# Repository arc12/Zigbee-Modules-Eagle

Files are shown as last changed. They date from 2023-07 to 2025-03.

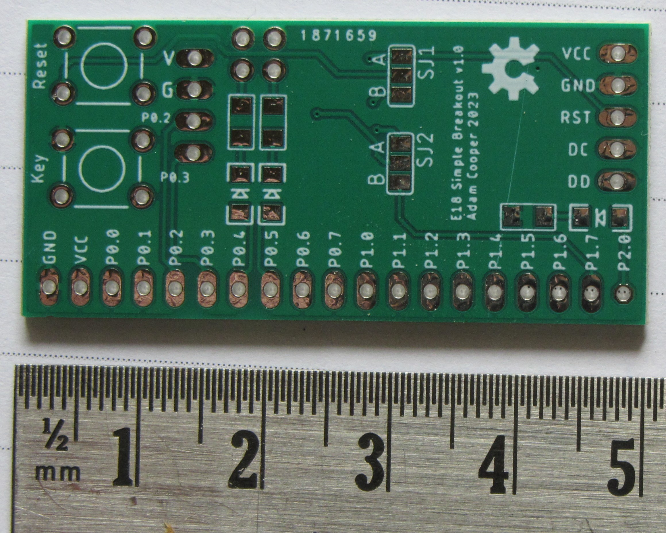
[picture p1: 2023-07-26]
E18 Front.JPG

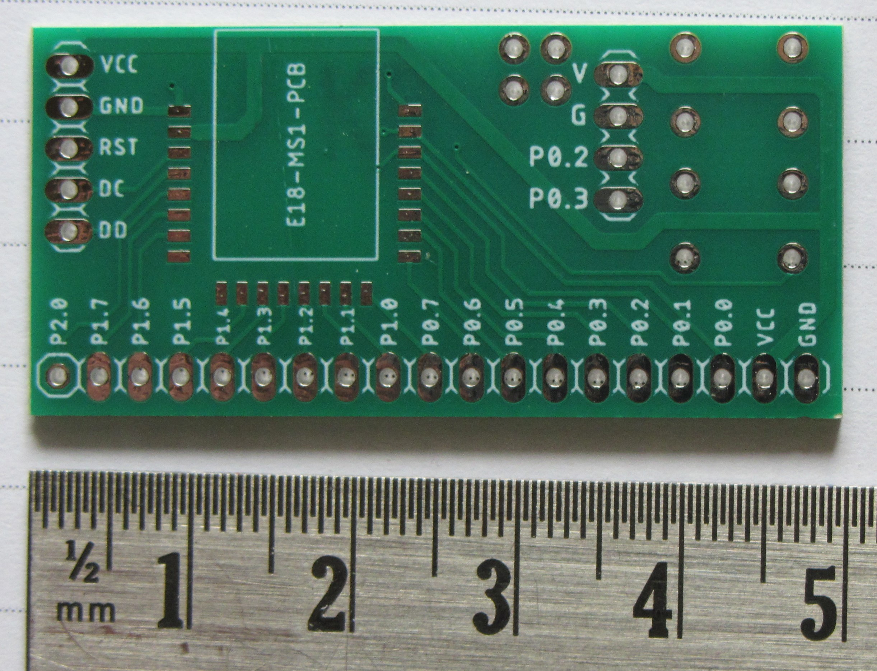
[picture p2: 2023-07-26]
E18 Rear.JPG

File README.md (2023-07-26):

# Zigbee Modules Eagle
## E18 Simple Breakout
A simple breakout board for the Ebyte E18 MS1 "stamp" module (i.e. a version without the extra power amplifier). The device shown is the PCB variant but AFAIK the landing pattern is identical for the IPX variant. The PA1/PA2 versions of E18 include a power amplifier and have a slightly larger landing pattern which probably won't fit (try at your own risk!).

This is "simple" in that the main use case is to plug into breadboard; although there are some components other than the E18 on the board, these are included for possible convenience (and using available board space).

Some notes on motivation, layout pragmatics, and options:
- The long header is meant to be populated with right-angle pins. This will put the antenna nicely up and leaves plenty of space for other components on the breadboard (I find the breakouts with very wide dual-in-line pin-outs to be rather irritating, and Arduino style sockets and flying leads are not great when more than a few connections are to be made).
- The 5 pin header is for firmware flashing. I opted for this, rather than the full 10 pin "debug" header which CCDebugger uses, for econonmy of space. These 5 pins are quite sufficient for using CCDebugger with TI SmartRF Flash Programmer (I made a little adapter) or if using something like https://github.com/jmichault/flash_cc2531 (or my patched version for use with Pi v1 GPIOs at https://github.com/arc12/flash_cc2531).
- The 4 pin header may be convenient for either UART or I2C connections. I'm expecting to be using PTVO and for the CC2530 it fixes UART pins to be P0.2 and P0.3. This header is meant to be mounted on the same side as the E18 module (opposite to switches).
- The switches should be configured using the solder jumpers.
  - SJ1 handles the "Reset" button: A connects to E18 Reset; B connects to P0.0.
  - SJ2 handles the "Key" button: A connects to P0.1; B connects to P1.7 (which is used by the E18 factory firmware).
- The on-board LEDs (and the enabling jumpers) should visually correlate with the pins they are connected to: P0.4, P0.5, and P2.0. These are NOT the same as used by the factory firmware. P2.0 LED has no enabling jumper.

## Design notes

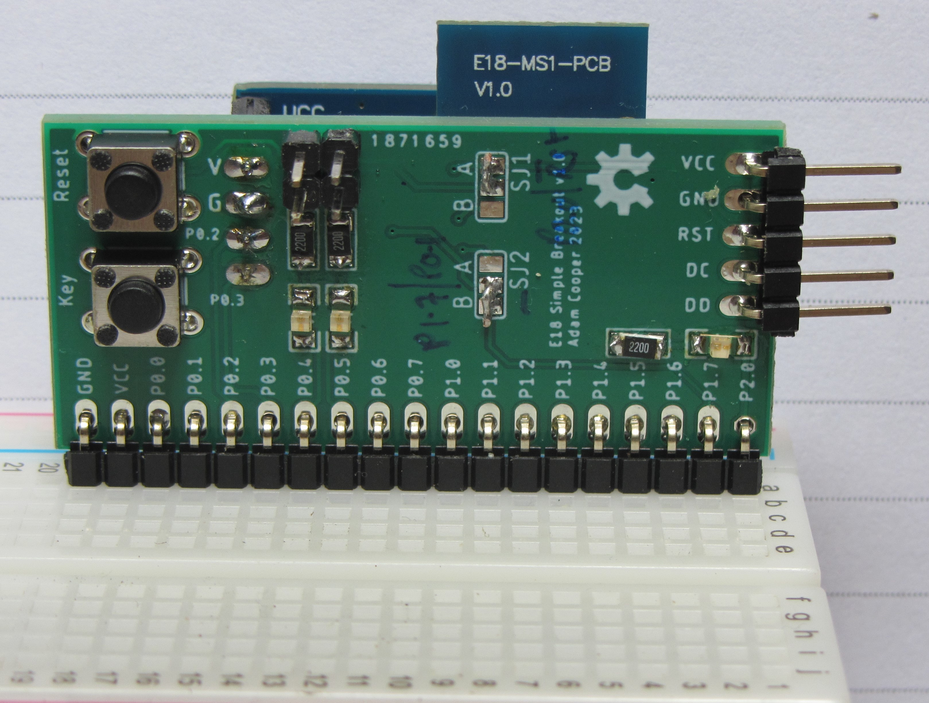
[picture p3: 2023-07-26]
E18 Populated.JPG

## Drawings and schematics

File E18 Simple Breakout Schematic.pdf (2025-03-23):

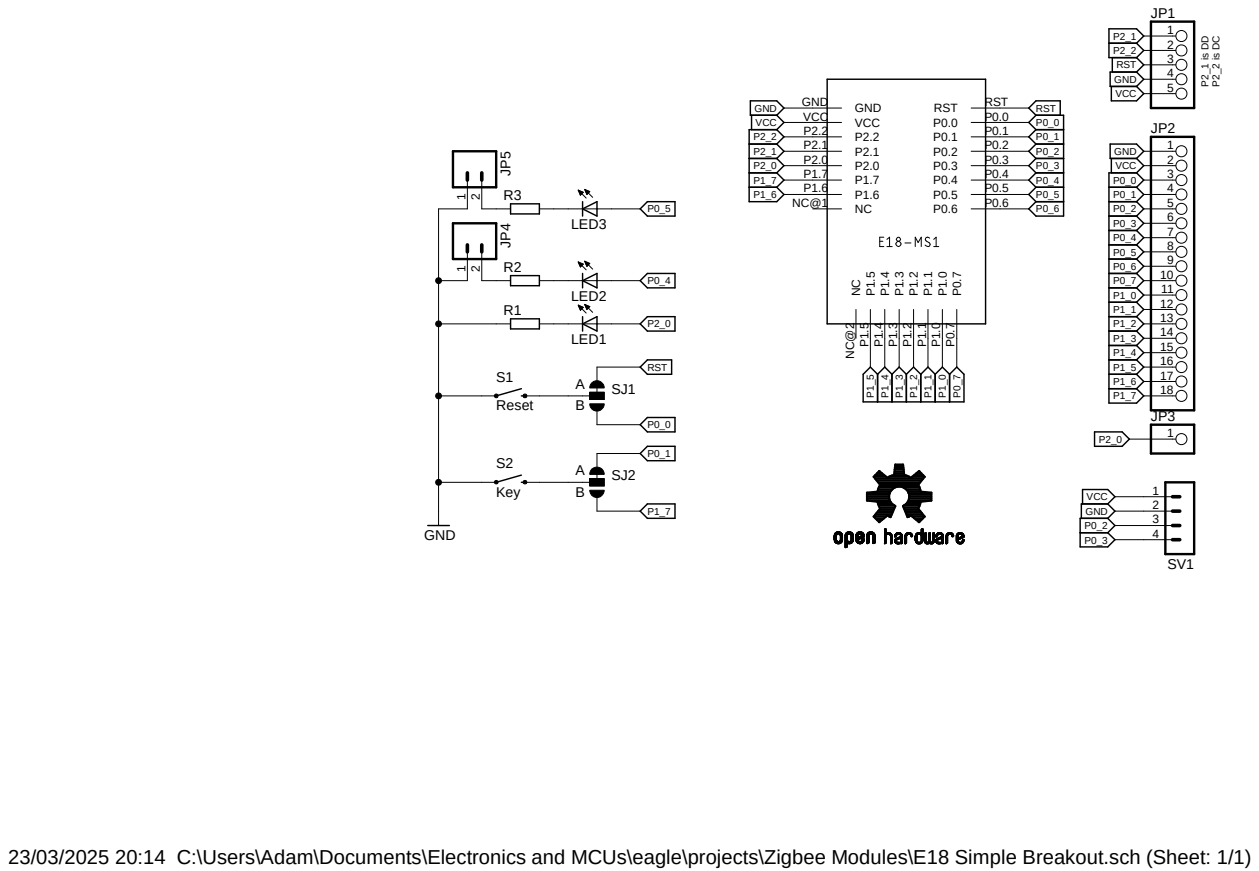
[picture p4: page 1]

23/03/2025 20:14 C:\Users\Adam\Documents\Electronics and MCUs\eagle\projects\Zigbee Modules\E18 Simple Breakout.sch (Sheet: 1/1) P²_1 is DD P²_2 is DC

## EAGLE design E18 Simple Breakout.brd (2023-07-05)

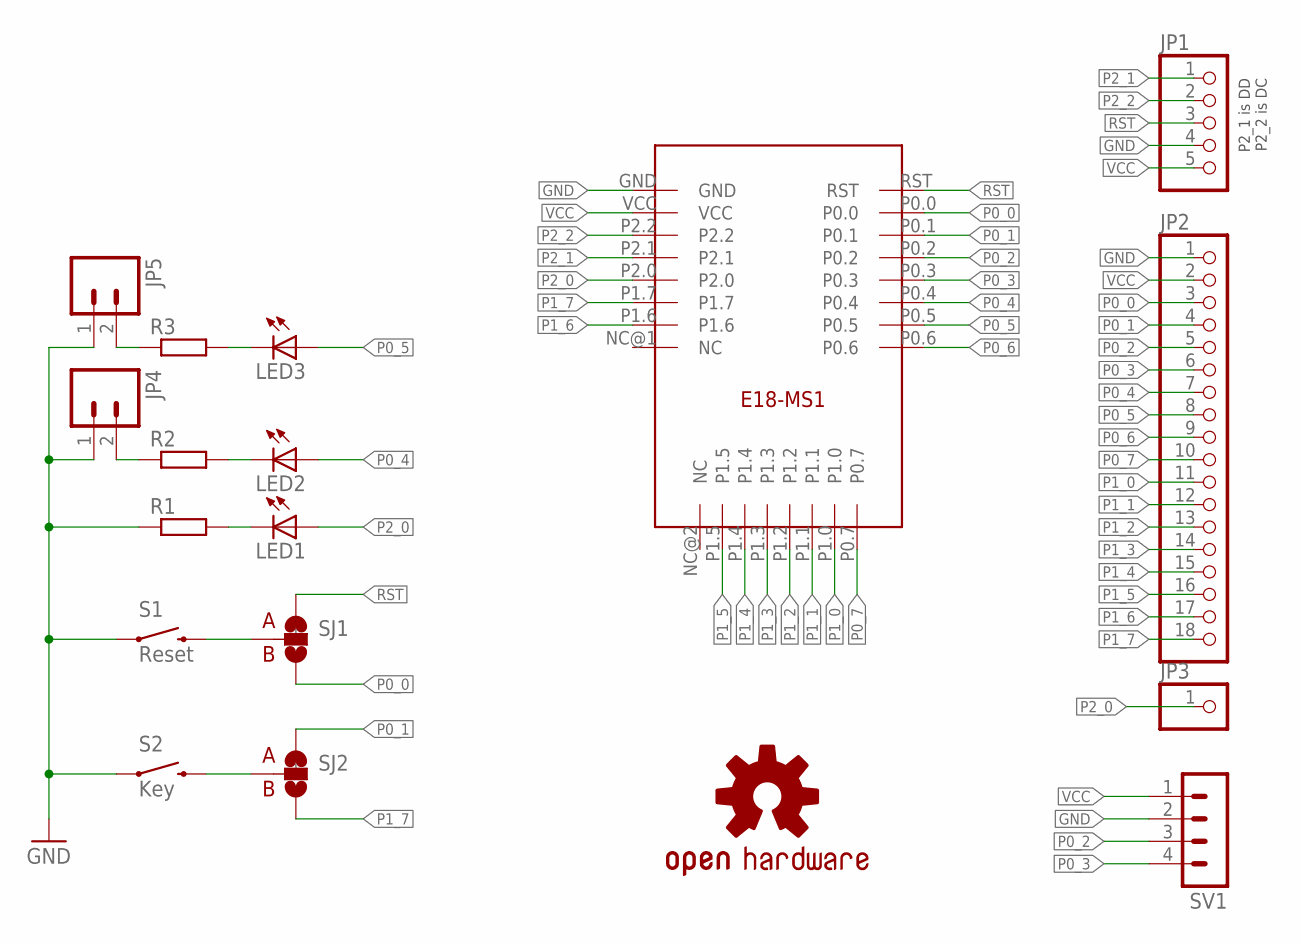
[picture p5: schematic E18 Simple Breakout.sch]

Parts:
JP1: PINHD-1X5; 1X05
JP2: PINHD-1X18; 1X18
JP3: PINHD-1X1; 1X01
JP4, JP5: HEADER-1X2P1X02_NO_SILK; 1X02_NO_SILK
LED1, LED2, LED3: LED1206; LED-1206
LOGO1: OSHW-LOGOM; OSHW-LOGO-M
R1, R2, R3: R-EU_; 1206
S1: Reset; TACTILE-PTH
S2: Key; TACTILE-PTH
SJ1, SJ2: SOLDERJUMPER_2WAYT; SJ_2
SV1: HEADER-1X4P; MA04-1
U$1: E18-MS1PCB; E18-MS1-PCB

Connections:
GND: JP1.4, JP2.1, JP4.1, JP5.1, R1.1, S1.1, S2.1, SV1.2, U$1.GND
unnamed: LED3.C, R3.2
unnamed: S1.3 (2), SJ1.2
unnamed: JP4.2, R2.1
unnamed: JP5.2, R3.1
unnamed: S2.3 (2), SJ2.2
unnamed: LED2.C, R2.2
unnamed: LED1.C, R1.2
P0_0: JP2.3, SJ1.3, U$1.P0.0
P0_1: JP2.4, SJ2.1, U$1.P0.1
P0_2: JP2.5, SV1.3, U$1.P0.2
P0_3: JP2.6, SV1.4, U$1.P0.3
P0_4: JP2.7, LED2.A, U$1.P0.4
P0_5: JP2.8, LED3.A, U$1.P0.5
P0_6: JP2.9, U$1.P0.6
P0_7: JP2.10, U$1.P0.7
P1_0: JP2.11, U$1.P1.0
P1_1: JP2.12, U$1.P1.1
P1_2: JP2.13, U$1.P1.2
P1_3: JP2.14, U$1.P1.3
P1_4: JP2.15, U$1.P1.4
P1_5: JP2.16, U$1.P1.5
P1_6: JP2.17, U$1.P1.6
P1_7: JP2.18, SJ2.3, U$1.P1.7
P2_0: JP3.1, LED1.A, U$1.P2.0
P2_1: JP1.1, U$1.P2.1
P2_2: JP1.2, U$1.P2.2
RST: JP1.3, SJ1.1, U$1.RST
VCC: JP1.5, JP2.2, SV1.1, U$1.VCC

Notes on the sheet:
P2_1 is DD P2_2 is DC

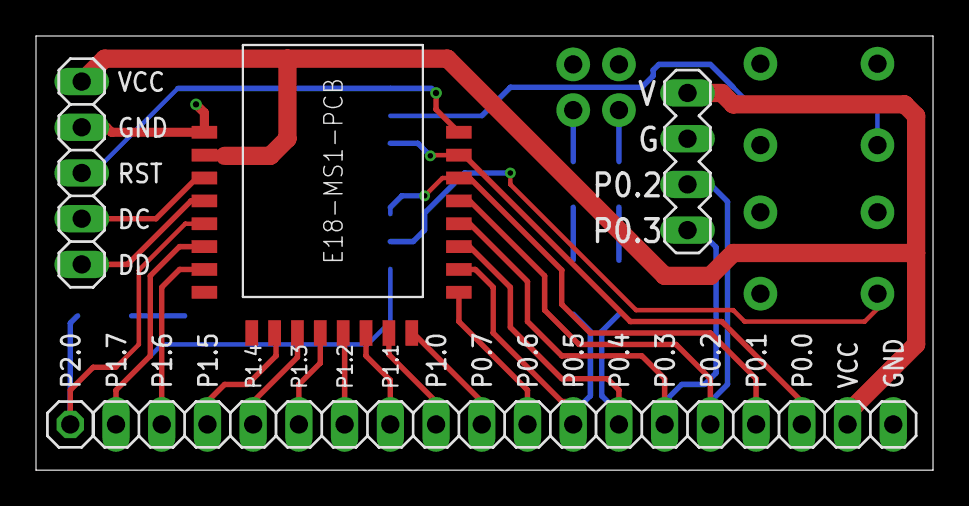
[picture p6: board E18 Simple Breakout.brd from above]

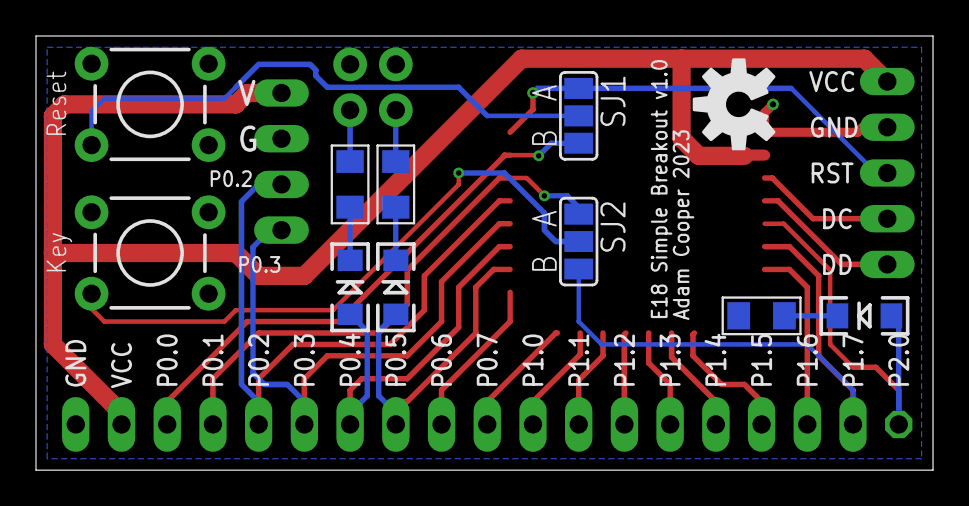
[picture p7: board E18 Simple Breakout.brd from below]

Board: 2 copper layers, 49.8 x 24.1 mm, 18 parts (11 on the bottom side), 29 nets.

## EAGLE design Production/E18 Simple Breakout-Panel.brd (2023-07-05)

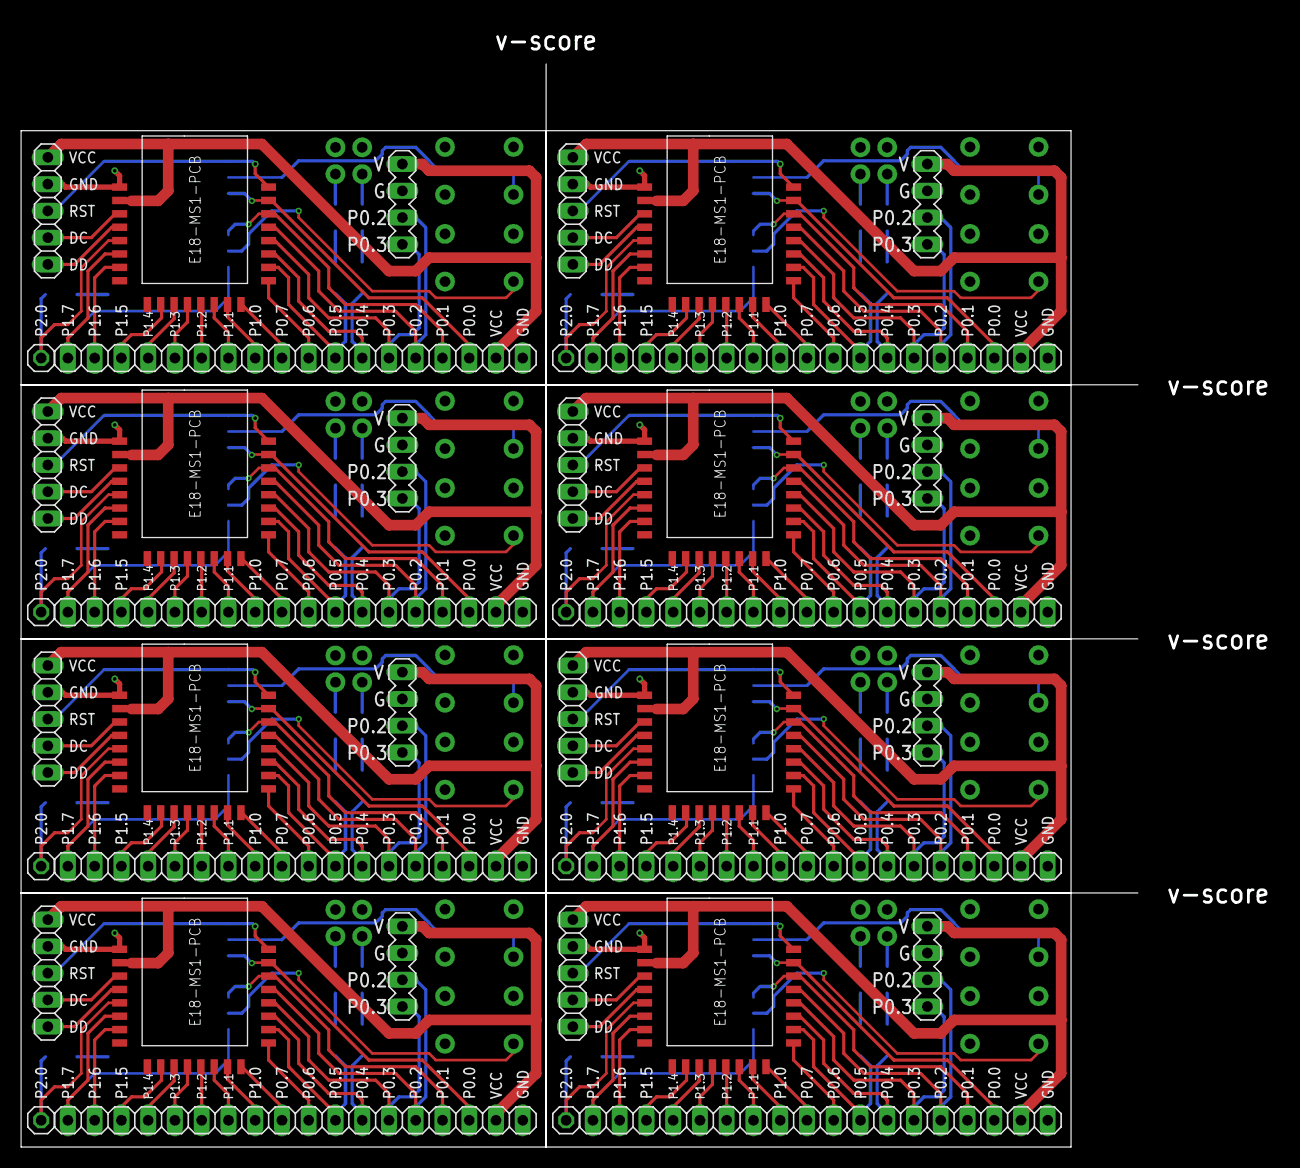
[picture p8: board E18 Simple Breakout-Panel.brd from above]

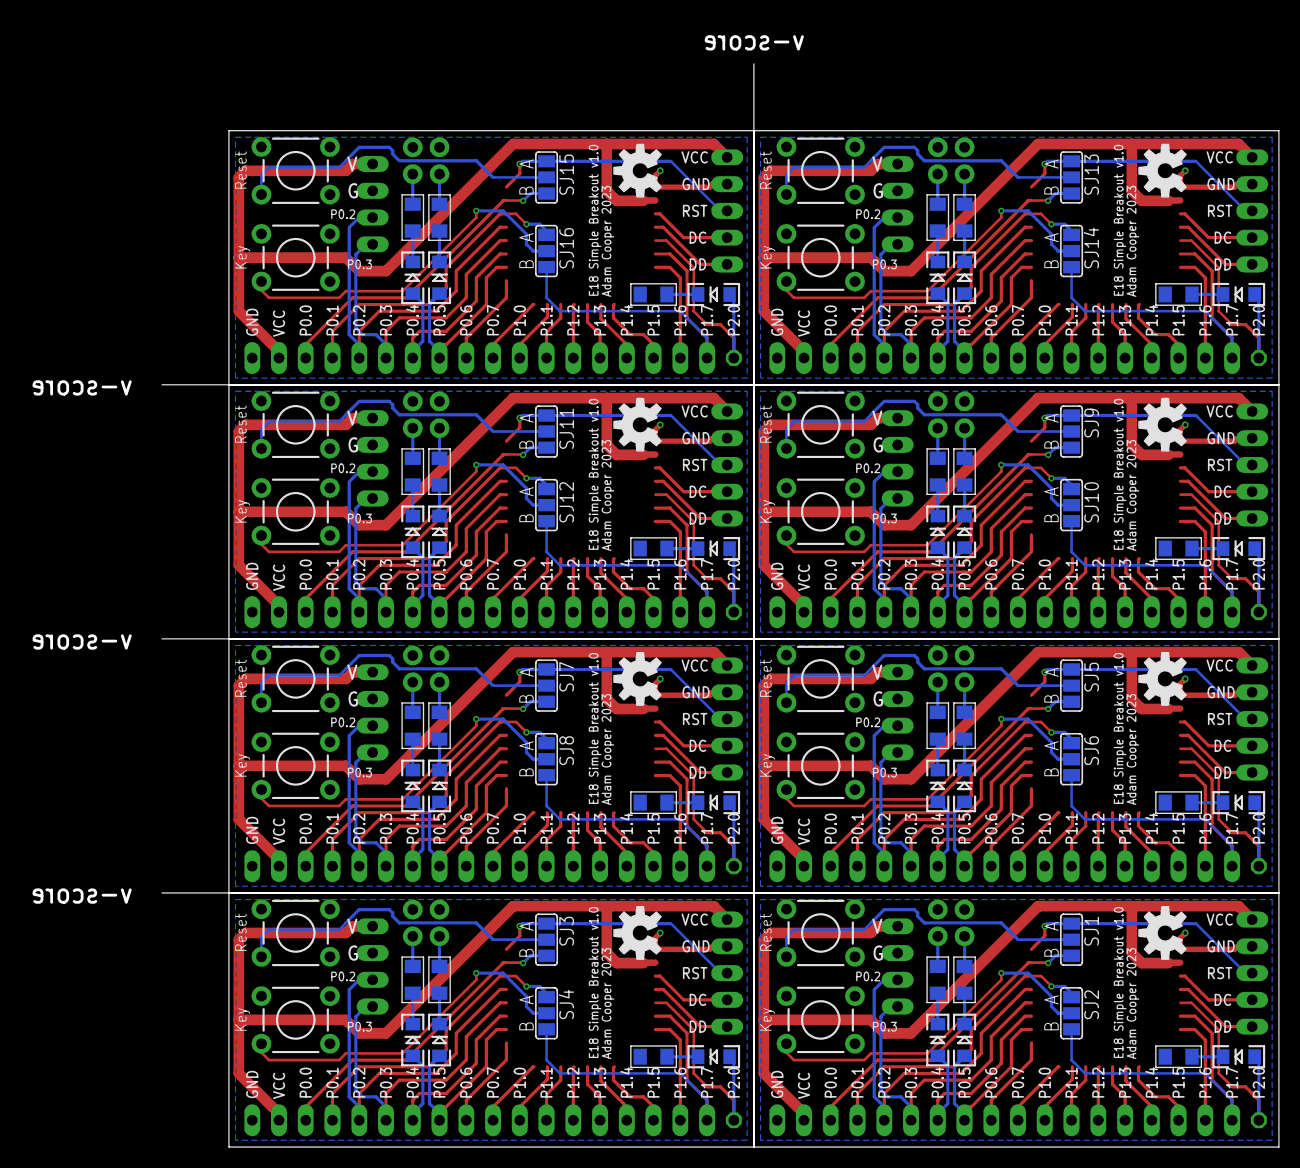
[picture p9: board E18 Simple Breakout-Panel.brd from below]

Board: 2 copper layers, 106.0 x 102.8 mm, 144 parts (88 on the bottom side), 232 nets.

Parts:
JP1, JP6, JP11, JP16, JP21, JP26, JP31, JP36: 1X05
JP2, JP8, JP13, JP18, JP23, JP28, JP33, JP38: 1X18
JP3, JP7, JP12, JP17, JP22, JP27, JP32, JP37: 1X01
JP4, JP5, JP9, JP10, JP14, JP15, JP19, JP20, JP24, JP25, JP29, JP30, JP34, JP35, JP39, JP40: 1X02_NO_SILK
LED1, LED2, LED3, LED4, LED5, LED6, LED7, LED8, LED9, LED10, LED11, LED12, LED13, LED14, LED15, LED16, LED17, LED18, LED19, LED20, LED21, LED22, LED23, LED24: LED-1206
LOGO1, LOGO2, LOGO3, LOGO4, LOGO5, LOGO6, LOGO7, LOGO8: OSHW-LOGOM; OSHW-LOGO-M
R1, R2, R3, R4, R5, R6, R7, R8, R9, R10, R11, R12, R13, R14, R15, R16, R17, R18, R19, R20, R21, R22, R23, R24: 1206
S1, S3, S5, S7, S9, S11, S13, S15: Reset; TACTILE-PTH
S2, S4, S6, S8, S10, S12, S14, S16: Key; TACTILE-PTH
SJ1, SJ2, SJ3, SJ4, SJ5, SJ6, SJ7, SJ8, SJ9, SJ10, SJ11, SJ12, SJ13, SJ14, SJ15, SJ16: SJ_2
SV1, SV2, SV3, SV4, SV5, SV6, SV7, SV8: MA04-1
U$1, U$2, U$3, U$4, U$5, U$6, U$7, U$8: E18-MS1PCB; E18-MS1-PCB

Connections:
GND: JP1.4, JP2.1, JP4.1, JP5.1, R1.1, S1.1, S2.1, SV1.2, U$1.GND
GND1: JP6.4, JP8.1, JP9.1, JP10.1, R4.1, S3.1, S4.1, SV2.2, U$2.GND
GND2: JP11.4, JP13.1, JP14.1, JP15.1, R7.1, S5.1, S6.1, SV3.2, U$3.GND
GND3: JP16.4, JP18.1, JP19.1, JP20.1, R10.1, S7.1, S8.1, SV4.2, U$4.GND
GND4: JP21.4, JP23.1, JP24.1, JP25.1, R13.1, S9.1, S10.1, SV5.2, U$5.GND
GND5: JP26.4, JP28.1, JP29.1, JP30.1, R16.1, S11.1, S12.1, SV6.2, U$6.GND
GND6: JP31.4, JP33.1, JP34.1, JP35.1, R19.1, S13.1, S14.1, SV7.2, U$7.GND
GND7: JP36.4, JP38.1, JP39.1, JP40.1, R22.1, S15.1, S16.1, SV8.2, U$8.GND
unnamed: LED3.C, R3.2
unnamed: S1.3, SJ1.2
unnamed: JP4.2, R2.1
unnamed: JP5.2, R3.1
unnamed: S2.3, SJ2.2
unnamed: LED2.C, R2.2
unnamed: LED1.C, R1.2
unnamed: S3.3, SJ3.2
unnamed: JP9.2, R5.1
unnamed: JP10.2, R6.1
unnamed: S4.3, SJ4.2
unnamed: LED6.C, R6.2
unnamed: LED5.C, R5.2
unnamed: LED4.C, R4.2
unnamed: S5.3, SJ5.2
unnamed: JP14.2, R8.1
unnamed: JP15.2, R9.1
unnamed: S6.3, SJ6.2
unnamed: LED9.C, R9.2
unnamed: LED8.C, R8.2
unnamed: LED7.C, R7.2
unnamed: S7.3, SJ7.2
unnamed: JP19.2, R11.1
unnamed: JP20.2, R12.1
unnamed: S8.3, SJ8.2
unnamed: LED12.C, R12.2
unnamed: LED11.C, R11.2
unnamed: LED10.C, R10.2
unnamed: S9.3, SJ9.2
unnamed: JP24.2, R14.1
unnamed: JP25.2, R15.1
unnamed: S10.3, SJ10.2
unnamed: LED15.C, R15.2
unnamed: LED14.C, R14.2
unnamed: LED13.C, R13.2
unnamed: S11.3, SJ11.2
unnamed: JP29.2, R17.1
unnamed: JP30.2, R18.1
unnamed: S12.3, SJ12.2
unnamed: LED18.C, R18.2
unnamed: LED17.C, R17.2
unnamed: LED16.C, R16.2
unnamed: S13.3, SJ13.2
unnamed: JP34.2, R20.1
unnamed: JP35.2, R21.1
unnamed: S14.3, SJ14.2
unnamed: LED21.C, R21.2
unnamed: LED20.C, R20.2
unnamed: LED19.C, R19.2
unnamed: S15.3, SJ15.2
unnamed: JP39.2, R23.1
unnamed: JP40.2, R24.1
unnamed: S16.3, SJ16.2
unnamed: LED24.C, R24.2
unnamed: LED23.C, R23.2
unnamed: LED22.C, R22.2
P0_0: JP2.3, SJ1.3, U$1.P0.0
P0_1: JP2.4, SJ2.1, U$1.P0.1
P0_2: JP2.5, SV1.3, U$1.P0.2
P0_3: JP2.6, SV1.4, U$1.P0.3
P0_4: JP2.7, LED2.A, U$1.P0.4
P0_5: JP2.8, LED3.A, U$1.P0.5
P0_6: JP2.9, U$1.P0.6
P0_7: JP2.10, U$1.P0.7
P0_8: JP8.3, SJ3.3, U$2.P0.0
P0_9: JP8.4, SJ4.1, U$2.P0.1
P0_10: JP8.5, SV2.3, U$2.P0.2
P0_11: JP8.6, SV2.4, U$2.P0.3
P0_12: JP8.7, LED5.A, U$2.P0.4
P0_13: JP8.8, LED6.A, U$2.P0.5
P0_14: JP8.9, U$2.P0.6
P0_15: JP8.10, U$2.P0.7
P0_16: JP13.3, SJ5.3, U$3.P0.0
P0_17: JP13.4, SJ6.1, U$3.P0.1
P0_18: JP13.5, SV3.3, U$3.P0.2
P0_19: JP13.6, SV3.4, U$3.P0.3
P0_20: JP13.7, LED8.A, U$3.P0.4
P0_21: JP13.8, LED9.A, U$3.P0.5
P0_22: JP13.9, U$3.P0.6
P0_23: JP13.10, U$3.P0.7
P0_24: JP18.3, SJ7.3, U$4.P0.0
P0_25: JP18.4, SJ8.1, U$4.P0.1
P0_26: JP18.5, SV4.3, U$4.P0.2
P0_27: JP18.6, SV4.4, U$4.P0.3
P0_28: JP18.7, LED11.A, U$4.P0.4
P0_29: JP18.8, LED12.A, U$4.P0.5
P0_30: JP18.9, U$4.P0.6
P0_31: JP18.10, U$4.P0.7
P0_32: JP23.3, SJ9.3, U$5.P0.0
P0_33: JP23.4, SJ10.1, U$5.P0.1
P0_34: JP23.5, SV5.3, U$5.P0.2
P0_35: JP23.6, SV5.4, U$5.P0.3
P0_36: JP23.7, LED14.A, U$5.P0.4
P0_37: JP23.8, LED15.A, U$5.P0.5
P0_38: JP23.9, U$5.P0.6
P0_39: JP23.10, U$5.P0.7
P0_40: JP28.3, SJ11.3, U$6.P0.0
P0_41: JP28.4, SJ12.1, U$6.P0.1
P0_42: JP28.5, SV6.3, U$6.P0.2
P0_43: JP28.6, SV6.4, U$6.P0.3
P0_44: JP28.7, LED17.A, U$6.P0.4
P0_45: JP28.8, LED18.A, U$6.P0.5
P0_46: JP28.9, U$6.P0.6
P0_47: JP28.10, U$6.P0.7
P0_48: JP33.3, SJ13.3, U$7.P0.0
P0_49: JP33.4, SJ14.1, U$7.P0.1
P0_50: JP33.5, SV7.3, U$7.P0.2
P0_51: JP33.6, SV7.4, U$7.P0.3
P0_52: JP33.7, LED20.A, U$7.P0.4
P0_53: JP33.8, LED21.A, U$7.P0.5
P0_54: JP33.9, U$7.P0.6
P0_55: JP33.10, U$7.P0.7
P0_56: JP38.3, SJ15.3, U$8.P0.0
P0_57: JP38.4, SJ16.1, U$8.P0.1
P0_58: JP38.5, SV8.3, U$8.P0.2
P0_59: JP38.6, SV8.4, U$8.P0.3
P0_60: JP38.7, LED23.A, U$8.P0.4
P0_61: JP38.8, LED24.A, U$8.P0.5
P0_62: JP38.9, U$8.P0.6
P0_63: JP38.10, U$8.P0.7
P1_0: JP2.11, U$1.P1.0
P1_1: JP2.12, U$1.P1.1
P1_2: JP2.13, U$1.P1.2
P1_3: JP2.14, U$1.P1.3
P1_4: JP2.15, U$1.P1.4
P1_5: JP2.16, U$1.P1.5
P1_6: JP2.17, U$1.P1.6
P1_7: JP2.18, SJ2.3, U$1.P1.7
P1_8: JP8.18, SJ4.3, U$2.P1.7
P1_9: JP8.17, U$2.P1.6
P1_10: JP8.16, U$2.P1.5
P1_11: JP8.15, U$2.P1.4
P1_12: JP8.14, U$2.P1.3
P1_13: JP8.13, U$2.P1.2
P1_14: JP8.12, U$2.P1.1
P1_15: JP8.11, U$2.P1.0
P1_16: JP13.18, SJ6.3, U$3.P1.7
P1_17: JP13.17, U$3.P1.6
P1_18: JP13.16, U$3.P1.5
P1_19: JP13.15, U$3.P1.4
P1_20: JP13.14, U$3.P1.3
P1_21: JP13.13, U$3.P1.2
P1_22: JP13.12, U$3.P1.1
P1_23: JP13.11, U$3.P1.0
P1_24: JP18.18, SJ8.3, U$4.P1.7
P1_25: JP18.17, U$4.P1.6
P1_26: JP18.16, U$4.P1.5
P1_27: JP18.15, U$4.P1.4
P1_28: JP18.14, U$4.P1.3
P1_29: JP18.13, U$4.P1.2
P1_30: JP18.12, U$4.P1.1
P1_31: JP18.11, U$4.P1.0
P1_32: JP23.18, SJ10.3, U$5.P1.7
P1_33: JP23.17, U$5.P1.6
P1_34: JP23.16, U$5.P1.5
P1_35: JP23.15, U$5.P1.4
P1_36: JP23.14, U$5.P1.3
P1_37: JP23.13, U$5.P1.2
P1_38: JP23.12, U$5.P1.1
P1_39: JP23.11, U$5.P1.0
P1_40: JP28.18, SJ12.3, U$6.P1.7
P1_41: JP28.17, U$6.P1.6
P1_42: JP28.16, U$6.P1.5
P1_43: JP28.15, U$6.P1.4
P1_44: JP28.14, U$6.P1.3
P1_45: JP28.13, U$6.P1.2
P1_46: JP28.12, U$6.P1.1
P1_47: JP28.11, U$6.P1.0
P1_48: JP33.18, SJ14.3, U$7.P1.7
P1_49: JP33.17, U$7.P1.6
P1_50: JP33.16, U$7.P1.5
P1_51: JP33.15, U$7.P1.4
P1_52: JP33.14, U$7.P1.3
P1_53: JP33.13, U$7.P1.2
P1_54: JP33.12, U$7.P1.1
P1_55: JP33.11, U$7.P1.0
P1_56: JP38.18, SJ16.3, U$8.P1.7
P1_57: JP38.17, U$8.P1.6
P1_58: JP38.16, U$8.P1.5
P1_59: JP38.15, U$8.P1.4
P1_60: JP38.14, U$8.P1.3
P1_61: JP38.13, U$8.P1.2
P1_62: JP38.12, U$8.P1.1
P1_63: JP38.11, U$8.P1.0
P2_0: JP3.1, LED1.A, U$1.P2.0
P2_1: JP1.1, U$1.P2.1
P2_2: JP1.2, U$1.P2.2
P2_3: JP6.2, U$2.P2.2
P2_4: JP6.1, U$2.P2.1
P2_5: JP7.1, LED4.A, U$2.P2.0
P2_6: JP11.2, U$3.P2.2
P2_7: JP11.1, U$3.P2.1
P2_8: JP12.1, LED7.A, U$3.P2.0
P2_9: JP16.2, U$4.P2.2
P2_10: JP16.1, U$4.P2.1
P2_11: JP17.1, LED10.A, U$4.P2.0
P2_12: JP21.2, U$5.P2.2
P2_13: JP21.1, U$5.P2.1
P2_14: JP22.1, LED13.A, U$5.P2.0
P2_15: JP26.2, U$6.P2.2
P2_16: JP26.1, U$6.P2.1
P2_17: JP27.1, LED16.A, U$6.P2.0
P2_18: JP31.2, U$7.P2.2
P2_19: JP31.1, U$7.P2.1
P2_20: JP32.1, LED19.A, U$7.P2.0
P2_21: JP36.2, U$8.P2.2
P2_22: JP36.1, U$8.P2.1
P2_23: JP37.1, LED22.A, U$8.P2.0
RST: JP1.3, SJ1.1, U$1.RST
RST1: JP6.3, SJ3.1, U$2.RST
RST2: JP11.3, SJ5.1, U$3.RST
RST3: JP16.3, SJ7.1, U$4.RST
RST4: JP21.3, SJ9.1, U$5.RST
RST5: JP26.3, SJ11.1, U$6.RST
RST6: JP31.3, SJ13.1, U$7.RST
RST7: JP36.3, SJ15.1, U$8.RST
VCC: JP1.5, JP2.2, SV1.1, U$1.VCC
VCC1: JP6.5, JP8.2, SV2.1, U$2.VCC
VCC2: JP11.5, JP13.2, SV3.1, U$3.VCC
VCC3: JP16.5, JP18.2, SV4.1, U$4.VCC
VCC4: JP21.5, JP23.2, SV5.1, U$5.VCC
VCC5: JP26.5, JP28.2, SV6.1, U$6.VCC
VCC6: JP31.5, JP33.2, SV7.1, U$7.VCC
VCC7: JP36.5, JP38.2, SV8.1, U$8.VCC

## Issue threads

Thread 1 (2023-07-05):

Add support for E18 -MS1PA2

arc12, 2023-07-05:
This module has a larger footprint but I think it should be possible to use longer pads on the PCB so that either can be soldered. It might be necessary to make the board "Y" dimension a bit larger, or to remove/miniturise some of the main header labels on layer 1.

I should have thought of this before sending to Seeed!

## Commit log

2023-07-05 provisional v1.0 unpanelised
    [E18 Simple Breakout.brd, E18 Simple Breakout.sch]
2023-07-05 fix layer so panelisation works. incidentally now include the layers 122 and 126 from Tools > Panelize
    [E18 Simple Breakout.brd]
2023-07-05 add panelised board
    [E18 Simple Breakout-Panel.brd]
2025-03-23 add pdf of schematic
